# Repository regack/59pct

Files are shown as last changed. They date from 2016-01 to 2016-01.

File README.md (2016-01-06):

Regack's 59% Keyboard
=====

A reduced size keyboard, but not quite 60%.

This is the extended version of the 59% keyboard.  

* You can safely cut off the number pad section to remove the last 4 columns.  
* Locate the two small ground pads at the top and the bottom of the board.  
* Score along both front and back, and snap it off.

## v1.1 2016.01.05
Finally fixed the missing trace on S05:1 - on the ones I built I just soldered on a wire to bridge the missing gap.

## v1.0 2015-03-15
See here for more info : http://geekhack.org/index.php?topic=69978.0

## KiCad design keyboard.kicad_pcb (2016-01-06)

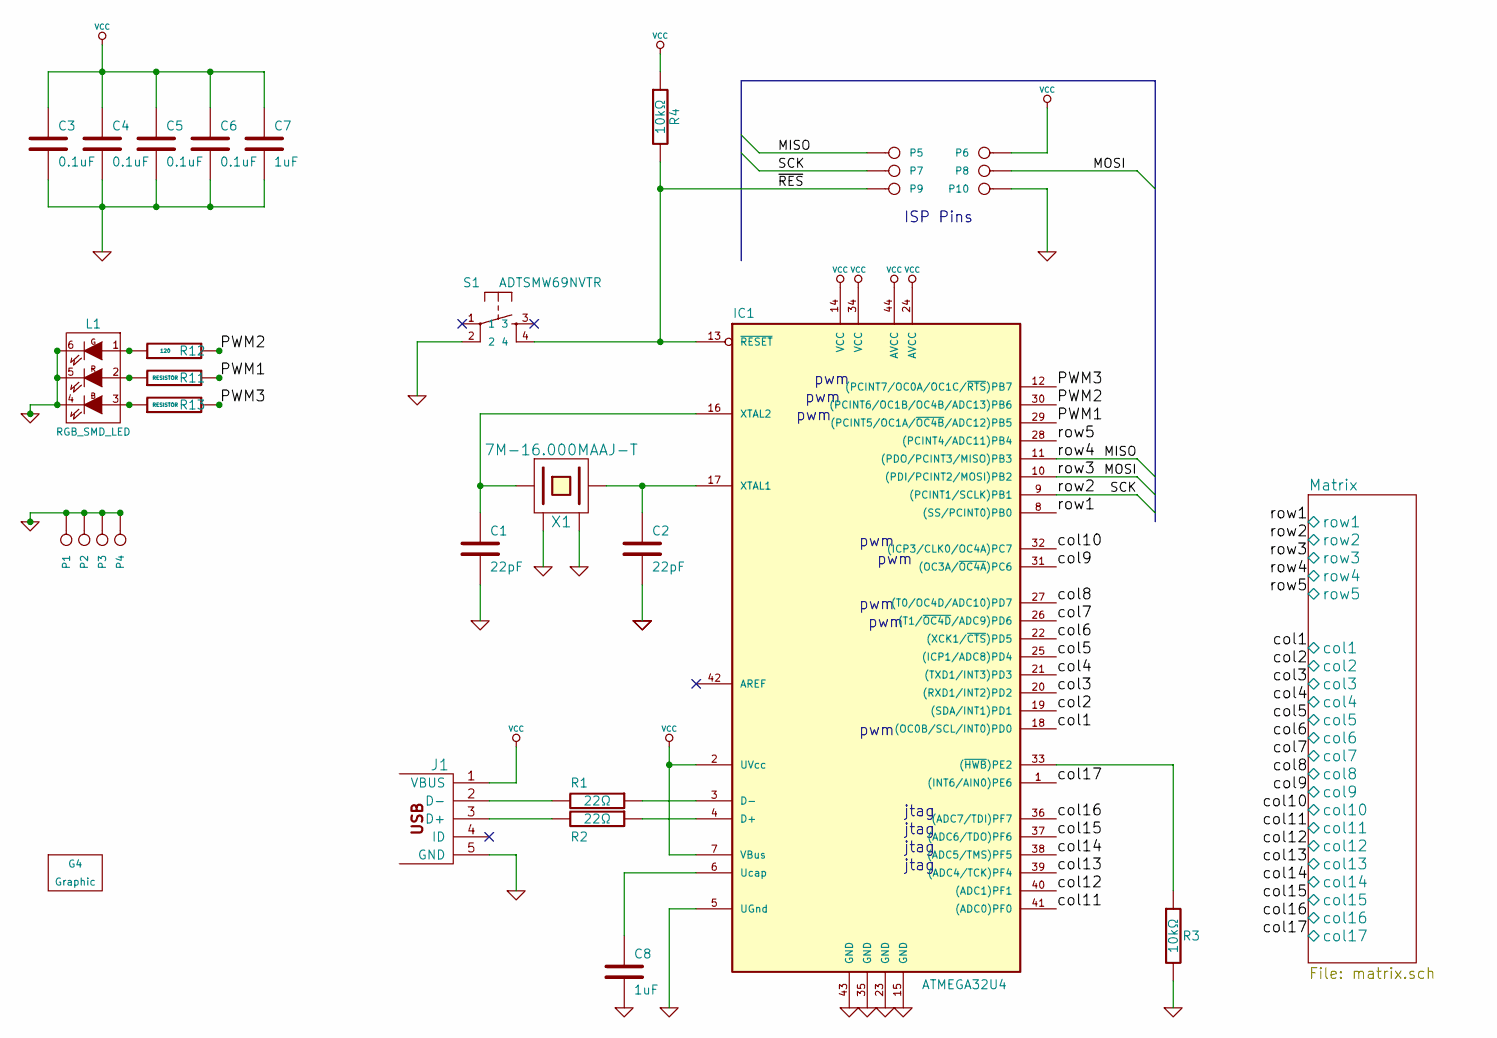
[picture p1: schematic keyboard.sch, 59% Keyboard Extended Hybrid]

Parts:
C1, C2: 22pF; 0804
C3, C4, C5, C6: 0.1uF; 0805
C7, C8: 1uF; 0805
G4: Graphic
IC1: ATMEGA32U4; TQFP44
J1: USB MINI-B
L1: RGB_SMD_LED
P1, P2, P3, P4, P10: GND
P5: MISO
P6: Vcc
P7: SCK
P8: MOSI
P9: RES
R1, R2: 22Ω; 0805
R3, R4: 10kΩ; 0805
R11, R13: RESISTOR
R12: 120
S1: ADTSMW69NVTR; switch-tact-DTSM-6
X1: 7M-16.000MAAJ-T

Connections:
/Matrix/col1: IC1.18 ((OC0B/SCL/INT0)PD0); also elsewhere on the board
/Matrix/col2: IC1.19 ((SDA/INT1)PD1); also elsewhere on the board
/Matrix/col3: IC1.20 ((RXD1/INT2)PD2); also elsewhere on the board
/Matrix/col4: IC1.21 ((TXD1/INT3)PD3); also elsewhere on the board
/Matrix/col5: IC1.25 ((ICP1/ADC8)PD4); also elsewhere on the board
/Matrix/col6: IC1.22 ((XCK1/~CTS~)PD5); also elsewhere on the board
/Matrix/col7: IC1.26 ((T1/~OC4D~/ADC9)PD6); also elsewhere on the board
/Matrix/col8: IC1.27 ((T0/OC4D/ADC10)PD7); also elsewhere on the board
/Matrix/col9: IC1.31 ((OC3A/~OC4A~)PC6); also elsewhere on the board
/Matrix/col10: IC1.32 ((ICP3/CLK0/OC4A)PC7); also elsewhere on the board
/Matrix/col11: IC1.41 ((ADC0)PF0); also elsewhere on the board
/Matrix/col12: IC1.40 ((ADC1)PF1); also elsewhere on the board
/Matrix/col13: IC1.39 ((ADC4/TCK)PF4); also elsewhere on the board
/Matrix/col14: IC1.38 ((ADC5/TMS)PF5); also elsewhere on the board
/Matrix/col15: IC1.37 ((ADC6/TDO)PF6); also elsewhere on the board
/Matrix/col16: IC1.36 ((ADC7/TDI)PF7); also elsewhere on the board
/Matrix/col17: IC1.1 ((INT6/AIN0)PE6); also elsewhere on the board
/Matrix/row1: IC1.8 ((SS/PCINT0)PB0); also elsewhere on the board
/Matrix/row2: IC1.9 ((PCINT1/SCLK)PB1), P7.1; also elsewhere on the board
/Matrix/row3: IC1.10 ((PDI/PCINT2/MOSI)PB2), P8.1; also elsewhere on the board
/Matrix/row4: IC1.11 ((PDO/PCINT3/MISO)PB3), P5.1; also elsewhere on the board
/Matrix/row5: IC1.28 ((PCINT4/ADC11)PB4); also elsewhere on the board
/PWM1: IC1.29 ((PCINT5/OC1A/~OC4B~/ADC12)PB5), R11.2
/PWM2: IC1.30 ((PCINT6/OC1B/OC4B/ADC13)PB6), R12.2
/PWM3: IC1.12 ((PCINT7/OC0A/OC1C/~RTS~)PB7), R13.2
/~RES~: IC1.13 (~RESET~), P9.1, R4.2, S1.4
GND: C1.2, C2.2, C3.2, C4.2, C5.2, C6.2, C7.2, C8.2, IC1.5 (UGnd), IC1.15 (GND), IC1.23 (GND), IC1.35 (GND), IC1.43 (GND), J1.5 (GND), L1.4 (K), L1.5 (K), L1.6 (K), P1.1, P2.1, P3.1, P4.1, P10.1, R3.2, S1.2, X1.2 (GND), X1.4 (GND)
unnamed: J1.2 (D-), R1.2
unnamed: J1.3 (D+), R2.2
unnamed: IC1.4 (D+), R2.1
unnamed: IC1.3 (D-), R1.1
unnamed: IC1.33 ((~HWB~)PE2), R3.1
unnamed: C8.1, IC1.6 (Ucap)
unnamed: L1.1 (A-Green), R12.1
unnamed: C1.1, IC1.16 (XTAL2), X1.1
unnamed: C2.1, IC1.17 (XTAL1), X1.3 (2)
unnamed: L1.3 (A-Blue), R13.1
unnamed: L1.2 (A-Red), R11.1
VCC: C3.1, C4.1, C5.1, C6.1, C7.1, IC1.2 (UVcc), IC1.7 (VBus), IC1.14 (VCC), IC1.24 (AVCC), IC1.34 (VCC), IC1.44 (AVCC), J1.1 (VBUS), P6.1, R4.1

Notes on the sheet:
ISP Pins
pwm
jtag

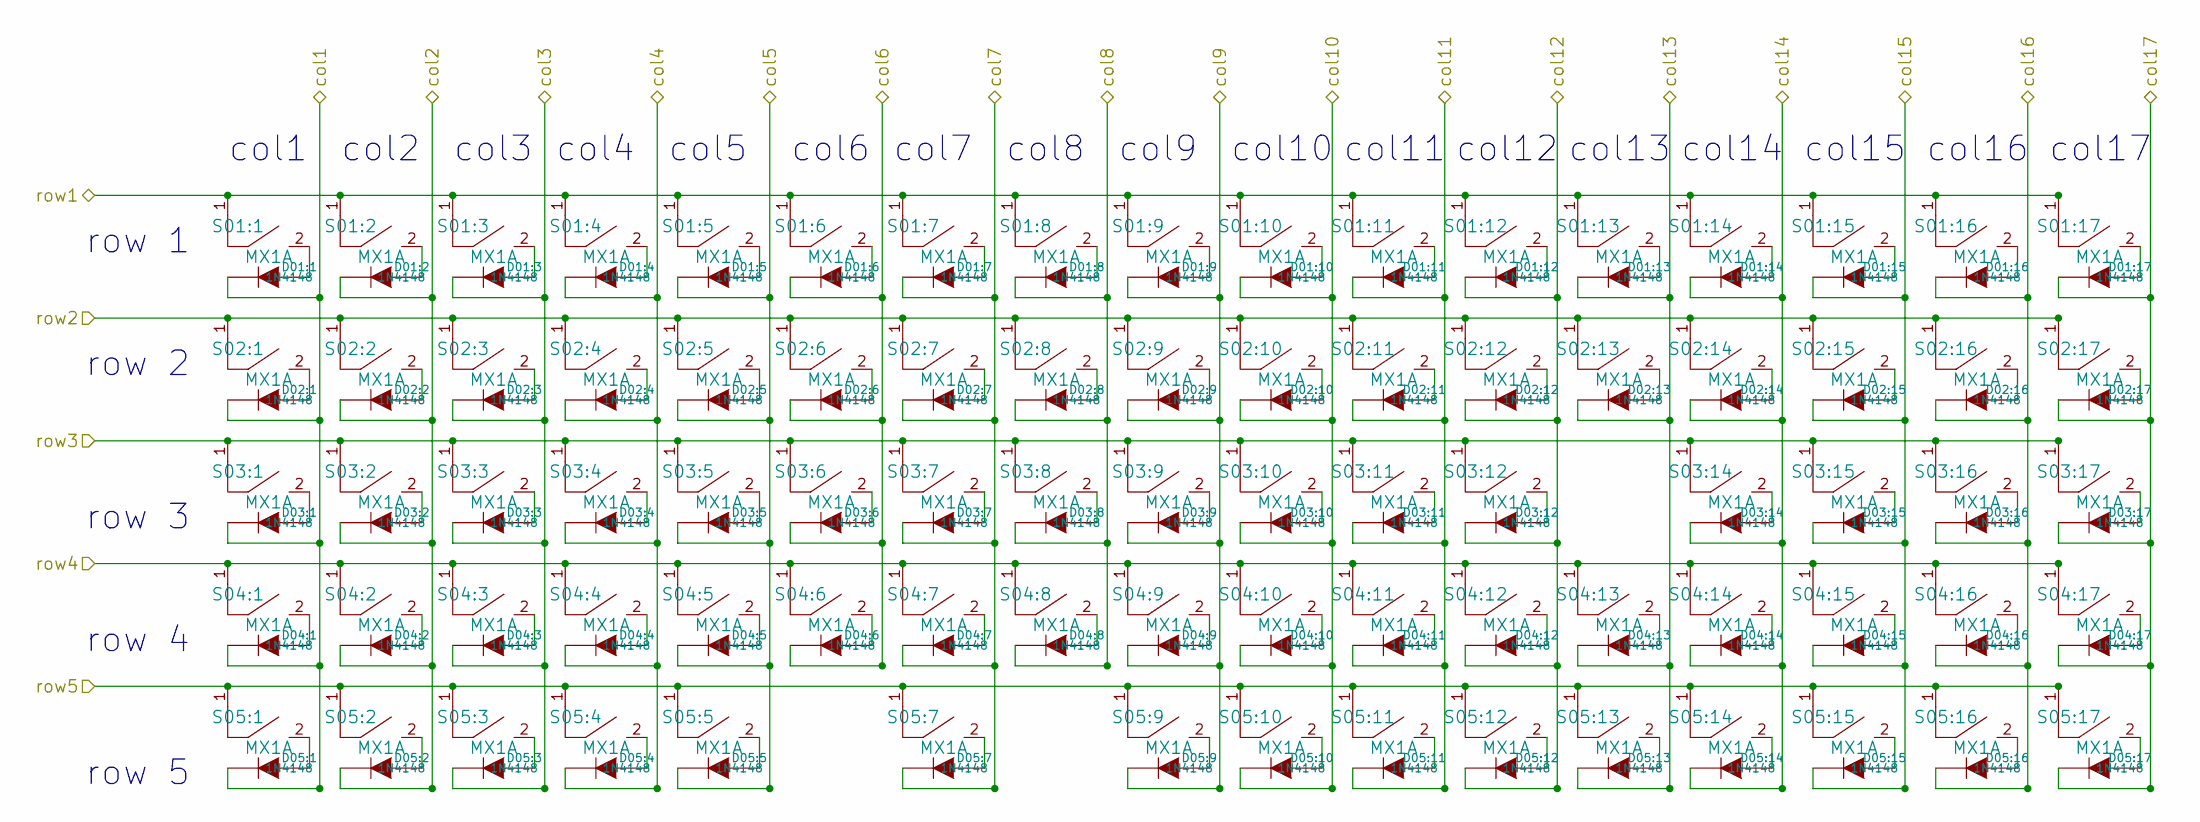
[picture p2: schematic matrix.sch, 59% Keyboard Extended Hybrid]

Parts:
D01:1, D01:2, D01:3, D01:4, D01:5, D01:6, D01:7, D01:8, D01:9, D01:10, D01:11, D01:12, D01:13, D01:14, D01:15, D01:16, D01:17, D02:1, D02:2, D02:3, D02:4, D02:5, D02:6, D02:7, D02:8, D02:9, D02:10, D02:11, D02:12, D02:13, D02:14, D02:15, D02:16, D02:17, D03:1, D03:2, D03:3, D03:4, D03:5, D03:6, D03:7, D03:8, D03:9, D03:10, D03:11, D03:12, D03:14, D03:15, D03:16, D03:17, D04:1, D04:2, D04:3, D04:4, D04:5, D04:6, D04:7, D04:8, D04:9, D04:10, D04:11, D04:12, D04:13, D04:14, D04:15, D04:16, D04:17, D05:1, D05:2, D05:3, D05:4, D05:5, D05:7, D05:9, D05:10, D05:11, D05:12, D05:13, D05:14, D05:15, D05:16, D05:17: 1N4148
S01:1, S01:2, S01:3, S01:4, S01:5, S01:6, S01:7, S01:8, S01:9, S01:10, S01:11, S01:12, S01:13, S01:14, S01:15, S01:16, S01:17, S02:1, S02:2, S02:3, S02:4, S02:5, S02:6, S02:7, S02:8, S02:9, S02:10, S02:11, S02:12, S02:13, S02:14, S02:15, S02:16, S02:17, S03:1, S03:2, S03:3, S03:4, S03:5, S03:6, S03:7, S03:8, S03:9, S03:10, S03:11, S03:12, S03:14, S03:15, S03:16, S03:17, S04:1, S04:2, S04:3, S04:4, S04:5, S04:6, S04:7, S04:8, S04:9, S04:10, S04:11, S04:12, S04:13, S04:14, S04:15, S04:16, S04:17, S05:1, S05:2, S05:3, S05:4, S05:5, S05:7, S05:9, S05:10, S05:11, S05:12, S05:13, S05:14, S05:15, S05:16, S05:17: MX1A

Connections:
/Matrix/col1: D01:1.C (K), D02:1.C (K), D03:1.C (K), D04:1.C (K), D05:1.C (K); also elsewhere on the board
/Matrix/col2: D01:2.C (K), D02:2.C (K), D03:2.C (K), D04:2.C (K), D05:2.C (K); also elsewhere on the board
/Matrix/col3: D01:3.C (K), D02:3.C (K), D03:3.C (K), D04:3.C (K), D05:3.C (K); also elsewhere on the board
/Matrix/col4: D01:4.C (K), D02:4.C (K), D03:4.C (K), D04:4.C (K), D05:4.C (K); also elsewhere on the board
/Matrix/col5: D01:5.C (K), D02:5.C (K), D03:5.C (K), D04:5.C (K), D05:5.C (K); also elsewhere on the board
/Matrix/col6: D01:6.C (K), D02:6.C (K), D03:6.C (K), D04:6.C (K); also elsewhere on the board
/Matrix/col7: D01:7.C (K), D02:7.C (K), D03:7.C (K), D04:7.C (K), D05:7.C (K); also elsewhere on the board
/Matrix/col8: D01:8.C (K), D02:8.C (K), D03:8.C (K), D04:8.C (K); also elsewhere on the board
/Matrix/col9: D01:9.C (K), D02:9.C (K), D03:9.C (K), D04:9.C (K), D05:9.C (K); also elsewhere on the board
/Matrix/col10: D01:10.C (K), D02:10.C (K), D03:10.C (K), D04:10.C (K), D05:10.C (K); also elsewhere on the board
/Matrix/col11: D01:11.C (K), D02:11.C (K), D03:11.C (K), D04:11.C (K), D05:11.C (K); also elsewhere on the board
/Matrix/col12: D01:12.C (K), D02:12.C (K), D03:12.C (K), D04:12.C (K), D05:12.C (K); also elsewhere on the board
/Matrix/col13: D01:13.C (K), D02:13.C (K), D04:13.C (K), D05:13.C (K); also elsewhere on the board
/Matrix/col14: D01:14.C (K), D02:14.C (K), D03:14.C (K), D04:14.C (K), D05:14.C (K); also elsewhere on the board
/Matrix/col15: D01:15.C (K), D02:15.C (K), D03:15.C (K), D04:15.C (K), D05:15.C (K); also elsewhere on the board
/Matrix/col16: D01:16.C (K), D02:16.C (K), D03:16.C (K), D04:16.C (K), D05:16.C (K); also elsewhere on the board
/Matrix/col17: D01:17.C (K), D02:17.C (K), D03:17.C (K), D04:17.C (K), D05:17.C (K); also elsewhere on the board
/Matrix/row1: S01:1.1, S01:2.1, S01:3.1, S01:4.1, S01:5.1, S01:6.1, S01:7.1, S01:8.1, S01:9.1, S01:10.1, S01:11.1, S01:12.1, S01:13.1, S01:14.1, S01:15.1, S01:16.1, S01:17.1; also elsewhere on the board
/Matrix/row2: S02:1.1, S02:2.1, S02:3.1, S02:4.1, S02:5.1, S02:6.1, S02:7.1, S02:8.1, S02:9.1, S02:10.1, S02:11.1, S02:12.1, S02:13.1, S02:14.1, S02:15.1, S02:16.1, S02:17.1; also elsewhere on the board
/Matrix/row3: S03:1.1, S03:2.1, S03:3.1, S03:4.1, S03:5.1, S03:6.1, S03:7.1, S03:8.1, S03:9.1, S03:10.1, S03:11.1, S03:12.1, S03:14.1, S03:15.1, S03:16.1, S03:17.1; also elsewhere on the board
/Matrix/row4: S04:1.1, S04:2.1, S04:3.1, S04:4.1, S04:5.1, S04:6.1, S04:7.1, S04:8.1, S04:9.1, S04:10.1, S04:11.1, S04:12.1, S04:13.1, S04:14.1, S04:15.1, S04:16.1, S04:17.1; also elsewhere on the board
/Matrix/row5: S05:1.1, S05:2.1, S05:3.1, S05:4.1, S05:5.1, S05:7.1, S05:9.1, S05:10.1, S05:11.1, S05:12.1, S05:13.1, S05:14.1, S05:15.1, S05:16.1, S05:17.1; also elsewhere on the board
unnamed: D04:1.A, S04:1.2
unnamed: D04:13.A, S04:13.2
unnamed: D05:11.A, S05:11.2
unnamed: D05:12.A, S05:12.2
unnamed: D05:13.A, S05:13.2
unnamed: D05:7.A, S05:7.2
unnamed: D03:1.A, S03:1.2
unnamed: D05:4.A, S05:4.2
unnamed: D05:1.A, S05:1.2
unnamed: D05:2.A, S05:2.2
unnamed: D05:3.A, S05:3.2
unnamed: D05:5.A, S05:5.2
unnamed: D05:9.A, S05:9.2
unnamed: D05:10.A, S05:10.2
unnamed: D03:12.A, S03:12.2
unnamed: D04:9.A, S04:9.2
unnamed: D04:10.A, S04:10.2
unnamed: D04:11.A, S04:11.2
unnamed: D04:12.A, S04:12.2
unnamed: D03:11.A, S03:11.2
unnamed: D02:13.A, S02:13.2
unnamed: D02:12.A, S02:12.2
unnamed: D02:5.A, S02:5.2
unnamed: D03:9.A, S03:9.2
unnamed: D02:9.A, S02:9.2
unnamed: D01:10.A, S01:10.2
unnamed: D01:13.A, S01:13.2
unnamed: D02:10.A, S02:10.2
unnamed: D01:11.A, S01:11.2
unnamed: D02:11.A, S02:11.2
unnamed: D03:10.A, S03:10.2
unnamed: D04:8.A, S04:8.2
unnamed: D01:12.A, S01:12.2
unnamed: D04:5.A, S04:5.2
unnamed: D04:7.A, S04:7.2
unnamed: D05:14.A, S05:14.2
unnamed: D05:15.A, S05:15.2
unnamed: D05:16.A, S05:16.2
unnamed: D05:17.A, S05:17.2
unnamed: D04:15.A, S04:15.2
unnamed: D04:16.A, S04:16.2
unnamed: D04:17.A, S04:17.2
unnamed: D01:16.A, S01:16.2
unnamed: D01:17.A, S01:17.2
unnamed: D02:14.A, S02:14.2
unnamed: D02:15.A, S02:15.2
unnamed: D01:14.A, S01:14.2
unnamed: D01:15.A, S01:15.2
unnamed: D03:15.A, S03:15.2
unnamed: D03:16.A, S03:16.2
unnamed: D03:17.A, S03:17.2
unnamed: D04:14.A, S04:14.2
unnamed: D02:16.A, S02:16.2
unnamed: D02:17.A, S02:17.2
unnamed: D03:14.A, S03:14.2
unnamed: D01:7.A, S01:7.2
unnamed: D01:9.A, S01:9.2
unnamed: D04:4.A, S04:4.2
unnamed: D02:2.A, S02:2.2
unnamed: D02:3.A, S02:3.2
unnamed: D02:4.A, S02:4.2
unnamed: D02:6.A, S02:6.2
unnamed: D02:7.A, S02:7.2
unnamed: D02:1.A, S02:1.2
unnamed: D02:8.A, S02:8.2
unnamed: D01:6.A, S01:6.2
unnamed: D01:1.A, S01:1.2
unnamed: D01:2.A, S01:2.2
unnamed: D01:3.A, S01:3.2
unnamed: D01:4.A, S01:4.2
unnamed: D01:5.A, S01:5.2
unnamed: D01:8.A, S01:8.2
unnamed: D04:2.A, S04:2.2
unnamed: D04:3.A, S04:3.2
unnamed: D04:6.A, S04:6.2
unnamed: D03:2.A, S03:2.2
unnamed: D03:3.A, S03:3.2
unnamed: D03:4.A, S03:4.2
unnamed: D03:5.A, S03:5.2
unnamed: D03:6.A, S03:6.2
unnamed: D03:7.A, S03:7.2
unnamed: D03:8.A, S03:8.2

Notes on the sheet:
row 1
row 2
row 3
row 4
row 5
col1
col2
col3
col4
col5
col6
col7
col9
col10
col11
col12
col13
col8
col14
col15
col16
col17

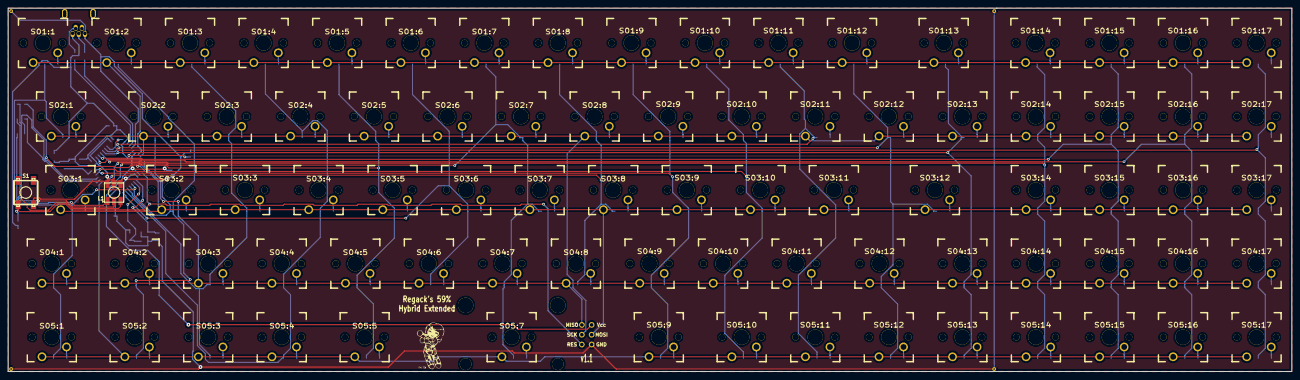
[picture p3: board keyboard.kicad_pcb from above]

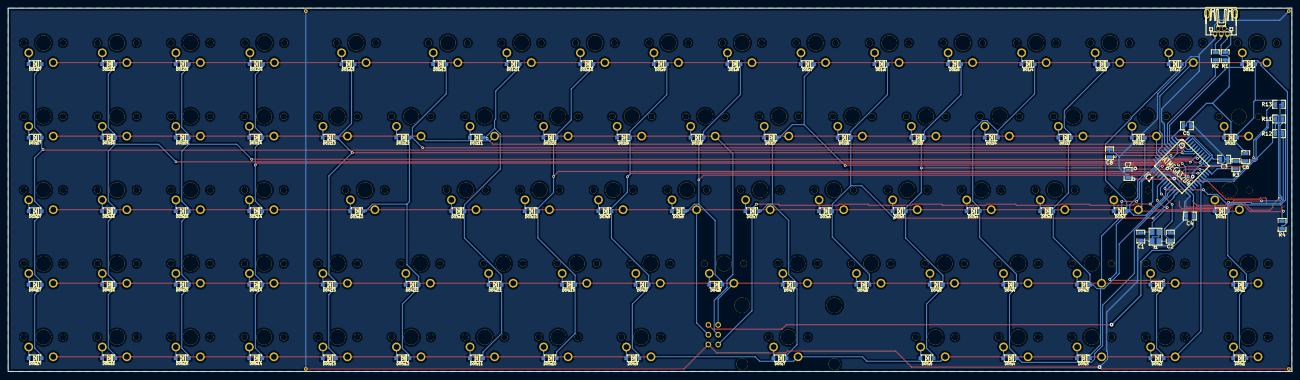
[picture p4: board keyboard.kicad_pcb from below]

Board: 2 copper layers, 332.5 x 94.1 mm, 195 parts (104 on the bottom side), 121 nets.
